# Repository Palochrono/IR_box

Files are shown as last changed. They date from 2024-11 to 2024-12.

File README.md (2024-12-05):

# IR_box
Normally open (HIGH) keychron low profile optical hitbox
Keychron switches footprint from [here](https://github.com/girishji/keychron-optical-keyboard?tab=MIT-1-ov-file)
## Part list
| Component | Description | Number_used |
| --- | --- | --- |
| R_IR | 180 $\Omega$ 0805 | 16 |
| R_PT | 2k $\Omega$ 0603 | 16 |
| Phototransistor | 0805 | 16 |
| IR_led | 0805 | 16 |
| Rp2040-zero | Waveshare | 1 |
| Pushbutton | 6*6mm | 4 |
| Key switches | Keychron optical low profile | 16 |
| OLED display | 0.96 inch I2C SSD1306 | 1 |
| Keycap set | DOIO KCGM-02 KCGM-03| 1 |
## Schematics and Render
Half-vias used to use the extra pins in rp2040-zero






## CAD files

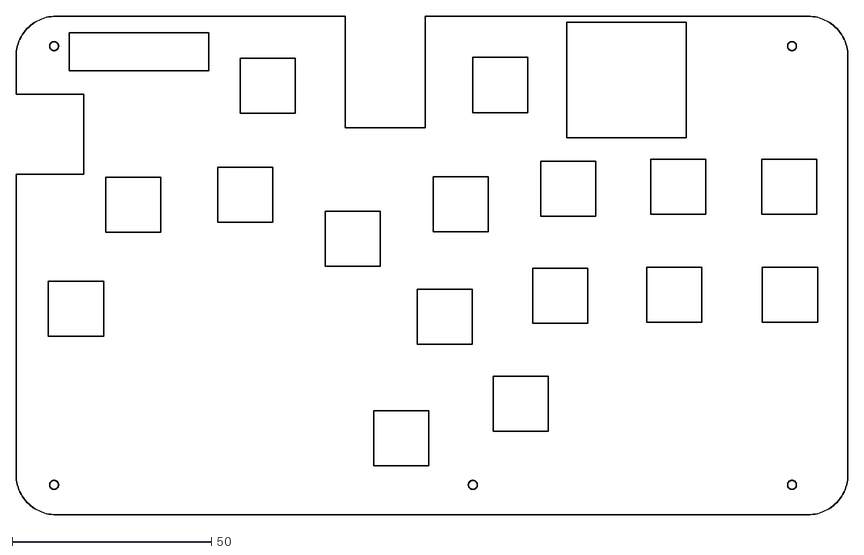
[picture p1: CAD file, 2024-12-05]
3d_files/dxf_files/switch_plate_1mm.dxf
208.5 x 125.0

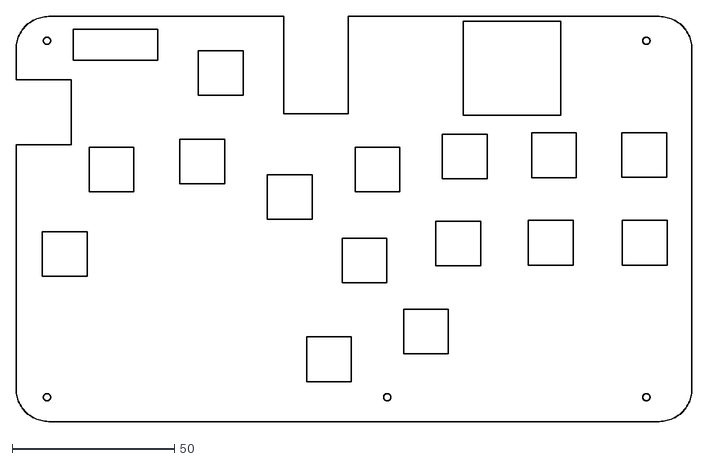
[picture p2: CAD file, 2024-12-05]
3d_files/dxf_files_1.0/switch_plate_1mm.dxf
208.5 x 125.0

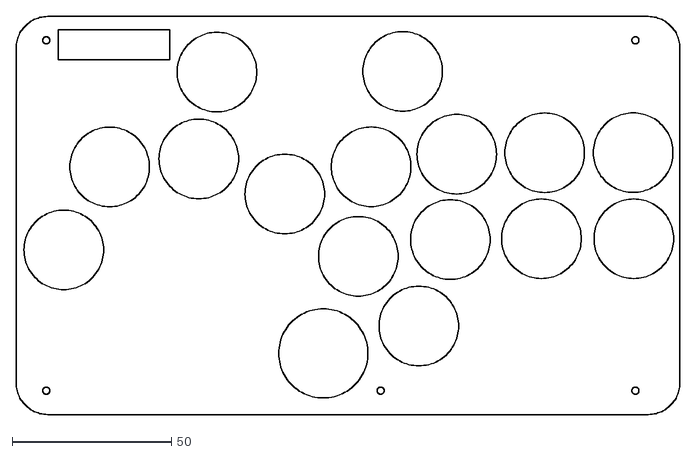
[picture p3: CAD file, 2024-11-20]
3d_files/top_cover_1.5mm.dxf
208.5 x 125.0

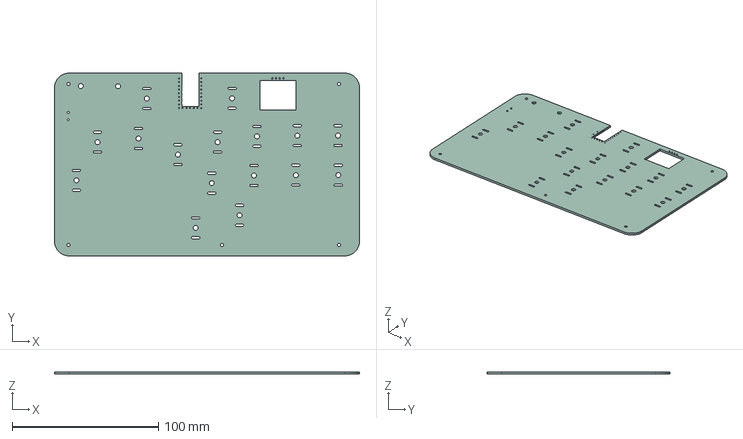
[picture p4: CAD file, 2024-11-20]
kicad/keychron_hitbox.step
208.5 x 125.0 x 1.69 mm

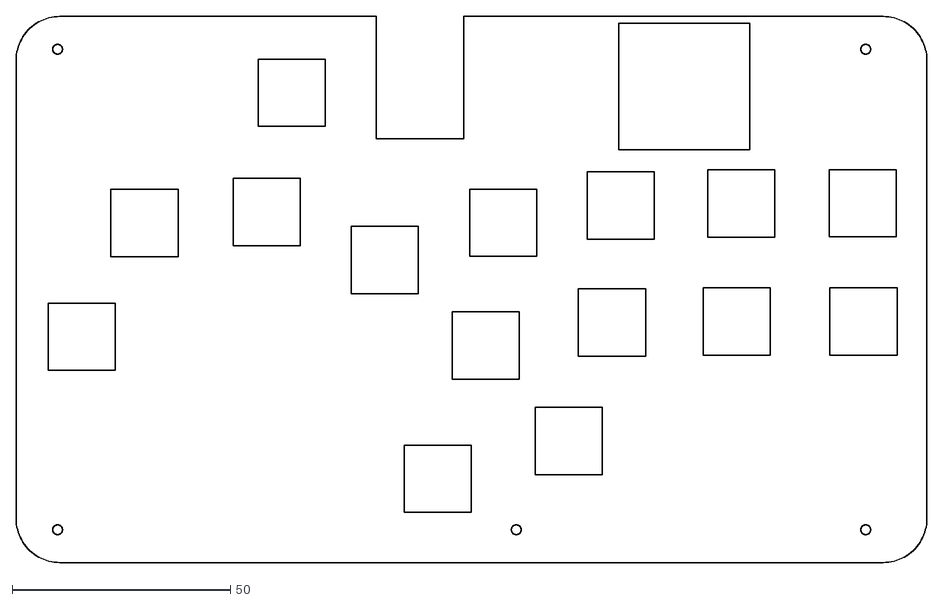
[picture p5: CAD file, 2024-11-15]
3d_files/dxf_files/switch_back_space_2mm.dxf
208.5 x 125.0

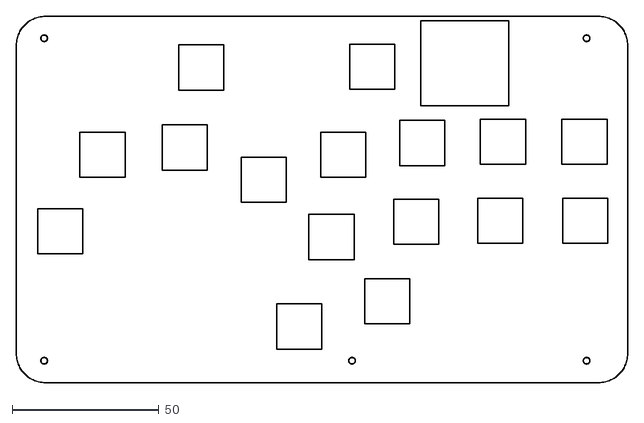
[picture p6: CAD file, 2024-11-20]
3d_files/dxf_files_upload/switch_back_space_1.5mm.dxf
208.5 x 125.0

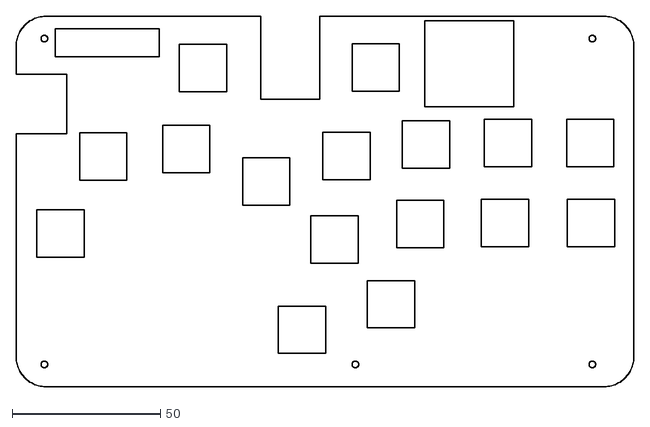
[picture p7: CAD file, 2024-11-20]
3d_files/switch_front_space_1.5mm.dxf
208.5 x 125.0

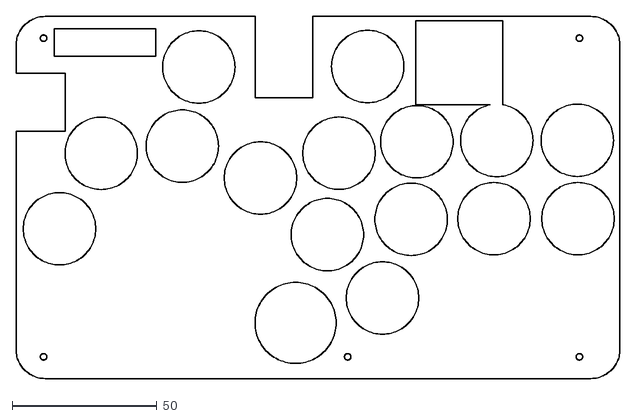
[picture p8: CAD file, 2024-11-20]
3d_files/switch_top_cover_space_4mm.dxf
208.5 x 125.0

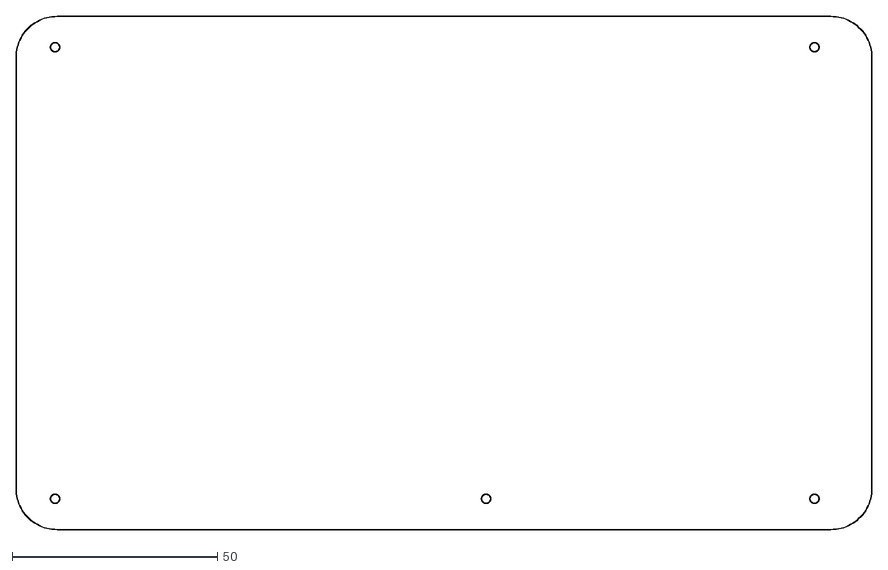
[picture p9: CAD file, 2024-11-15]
3d_files/dxf_files_upload/bottom_cover_1mm.dxf
208.5 x 125.0

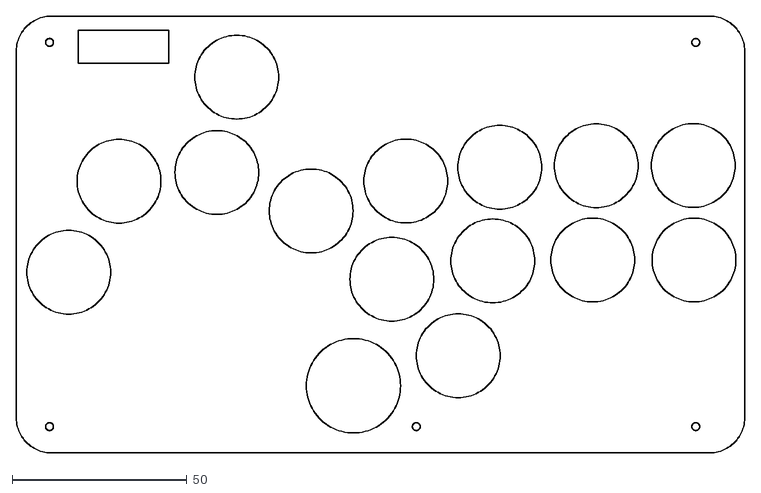
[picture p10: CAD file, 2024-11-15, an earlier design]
3d_files/older_version/dxf_files/top_cover_1.5mm.dxf
208.5 x 125.0

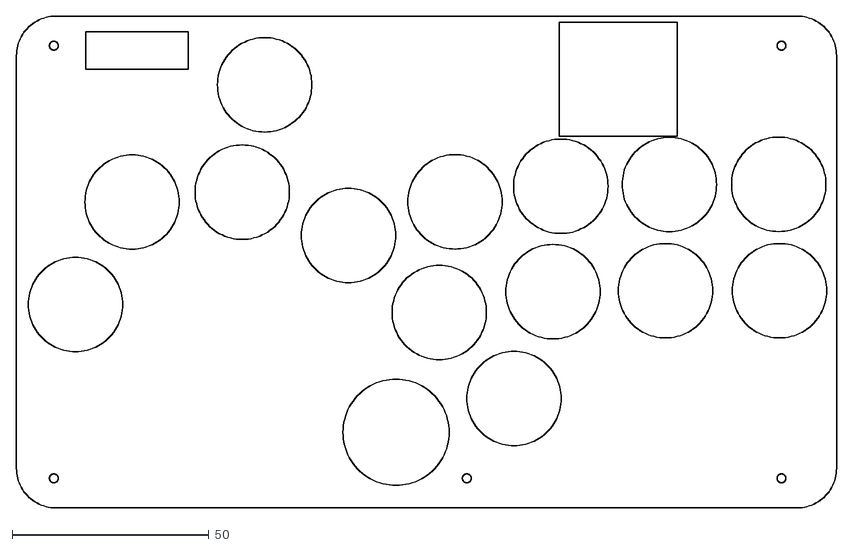
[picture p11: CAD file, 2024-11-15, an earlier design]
3d_files/older_version/dxf_files/switch_top_cover_space_4mm.dxf
208.5 x 125.0

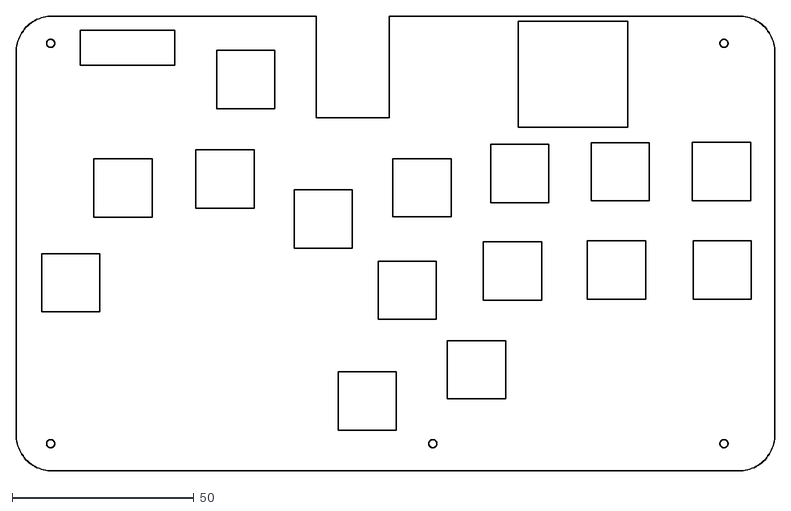
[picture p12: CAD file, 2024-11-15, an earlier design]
3d_files/older_version/dxf_files/switch_front_space_1.5mm.dxf
208.5 x 125.0

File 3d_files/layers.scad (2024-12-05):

$fn = 100;
module pcb(){
    translate([-43,150,0])
    import("/home/samz/programming/kicad/IR_box/kicad/Unnamed.stl");
}


module plainbase(x_size=208.5,y_size=125,corner_radius=10){
    translate([corner_radius,corner_radius,0])
    offset(r=corner_radius)
    square([x_size-2*corner_radius,y_size-2*corner_radius]);
}
//plainbase();

module hole(x_offset,y_offset,radius){
    translate([x_offset,y_offset,0])
    circle(radius);
}

module switch_plate_imprint(size = 13.8, catch_x = 3, catch_y=0){
    difference(){
        square(size, center=true);
        translate([0,size/2,0])
        square([catch_x,catch_y*2], center=true);
        translate([0,-size/2,0])
        square([catch_x,catch_y*2], center=true);
    }
}
module switch_plate_imprints(pos_array){
    for (a = [ 0 : len(pos_array) - 1 ]) 
    {
        point=pos_array[a];
        translate([point[0],point[1],0])
        switch_plate_imprint();
    }
}

module holes(pos_array,radius){
    for (a = [ 0 : len(pos_array) - 1 ]) 
    {
        point=pos_array[a];
        hole(point[0],point[1],radius);
    }
}

module squares(pos_array,size){
    for (a = [ 0 : len(pos_array) - 1 ]) 
    {
        point=pos_array[a];
        translate([point[0],point[1],0])
        square(size, center = true);
    }
}

screw_locations = [[9.5,7.5],[114.5,7.5],[194.5,7.5],[9.5,117.5],[194.5,117.5]];
//switch_locations = [[15,51.7],[29.4,77.75],[57.4,80.25],[63.1,107.55],[84.4,69.25],[107.5,49.685],[136.4,54.95],[165,55.2],[194,55.2],[193.8,82.25],[166,82.2],[138.4,81.75],[111.5,77.8],[126.5,27.8],[121.4,107.75]];
switch_locations = [[15,51.7],[29.4,77.75],[57.4,80.25],[63.1,107.55],[84.4,69.25],[107.5,49.685],[136.4,54.95],[165,55.2],[194,55.2],[193.8,82.25],[166,82.2],[138.4,81.75],[111.5,77.8],[126.5,27.8]];
jump_locations =[[96.5,19.2]];
//push_button_locations = [[27.,116.1],[34.55,116.1],[43.5,116.1],[18,116.1]];
push_button_locations = [[30.55,116.275],[38.9,116.275],[22.4,116.275]];

module push_button_holes(){
    squares(push_button_locations, 9.5);
    //squares(push_button_locations, 2.5);
}

module screw_holes(){
    holes(screw_locations, 1.12);
}
module 23mm_switch_circular(){
    holes(switch_locations, 12.5);
    //holes(switch_locations, 1.5);
}

module 26mm_switch_circular(){
    holes(jump_locations, 14);
}

module switches_back_slots(){
    squares(switch_locations, 15.4);
    squares(jump_locations, 15.4);
}

module switches_front_slots(){
    squares(switch_locations, 16);
    squares(jump_locations, 16);
}

module switch_plate_holes(){
    switch_plate_imprints(switch_locations);
    switch_plate_imprints(jump_locations);
}

module pi_imprint(){
    translate([82.5,97,0])
    square([20,28]);
}
module pi_imprint(){
    translate([82.5,95,0])
    square([20,30]);
}

module oled_imprint(){
    translate([138,94.5,0])
    square([30,29]);
}
module usb_imprint(){
    translate([0,85.4])
    square([17,20]);
}


module top_cover(){
    difference(){
        plainbase();
        push_button_holes();
        26mm_switch_circular();
        23mm_switch_circular();
        screw_holes();
    }
}
module bottom_cover(){
    difference(){
        plainbase();
        screw_holes();
    }
}
module switch_back_space(){
    difference(){
        plainbase();
        screw_holes();
        switches_back_slots();
        oled_imprint();
    }
}
module switch_front_space(){
    difference(){
        plainbase();
        push_button_holes();
        screw_holes();
        switches_front_slots();
        pi_imprint();
        oled_imprint();
        usb_imprint();
    }
}
module switch_front_plate(){
    difference(){
        plainbase();
        push_button_holes();
        screw_holes();
        switch_plate_holes();
        oled_imprint();
        pi_imprint();
        usb_imprint();
    }
}
module switch_top_cover_space(){
    difference(){
        plainbase();
        push_button_holes();
        26mm_switch_circular();
        23mm_switch_circular();
        screw_holes();
        oled_imprint();
        usb_imprint();
        pi_imprint();
    }
}

module testing_holes(){
    translate([10,50,0])
    switch_plate_imprint(size = 13.6, catch_x = 3, catch_y=0.2);
    translate([30,50,0])
    switch_plate_imprint(size = 13.7, catch_x = 3, catch_y=0.2);
    translate([50,50,0])
    switch_plate_imprint(size = 13.8, catch_x = 3, catch_y=0.2);
    translate([70,50,0])
    switch_plate_imprint(size = 13.9, catch_x = 3, catch_y=0.2);
    translate([90,50,0])
    switch_plate_imprint(size = 14.0, catch_x = 3, catch_y=0.2);
    translate([110,50,0])
    switch_plate_imprint(size = 14.1, catch_x = 3, catch_y=0.2);
    translate([130,50,0])
    switch_plate_imprint(size = 14.2, catch_x = 3, catch_y=0.2);
    translate([150,50,0])
    switch_plate_imprint(size = 14.3, catch_x = 3, catch_y=0.2);
    translate([170,50,0])
    switch_plate_imprint(size = 14.4, catch_x = 3, catch_y=0.2);
    translate([190,50,0])
    switch_plate_imprint(size = 14.5, catch_x = 3, catch_y=0.2);
}

module plate_test(){
    difference(){
        plainbase();
        push_button_holes();
        screw_holes();
        pi_imprint();
        oled_imprint();
        testing_holes();
    }
}
//bottom_cover();
//switch_back_space();
//switch_front_space();
switch_front_plate();
//switch_top_cover_space();
//pcb();
//top_cover();
//plate_test();

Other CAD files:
kicad/3d_files/layers.scad
kicad/Unnamed-keychron_hitbox.scad
3d_files/switch_plate_1mm.dxf

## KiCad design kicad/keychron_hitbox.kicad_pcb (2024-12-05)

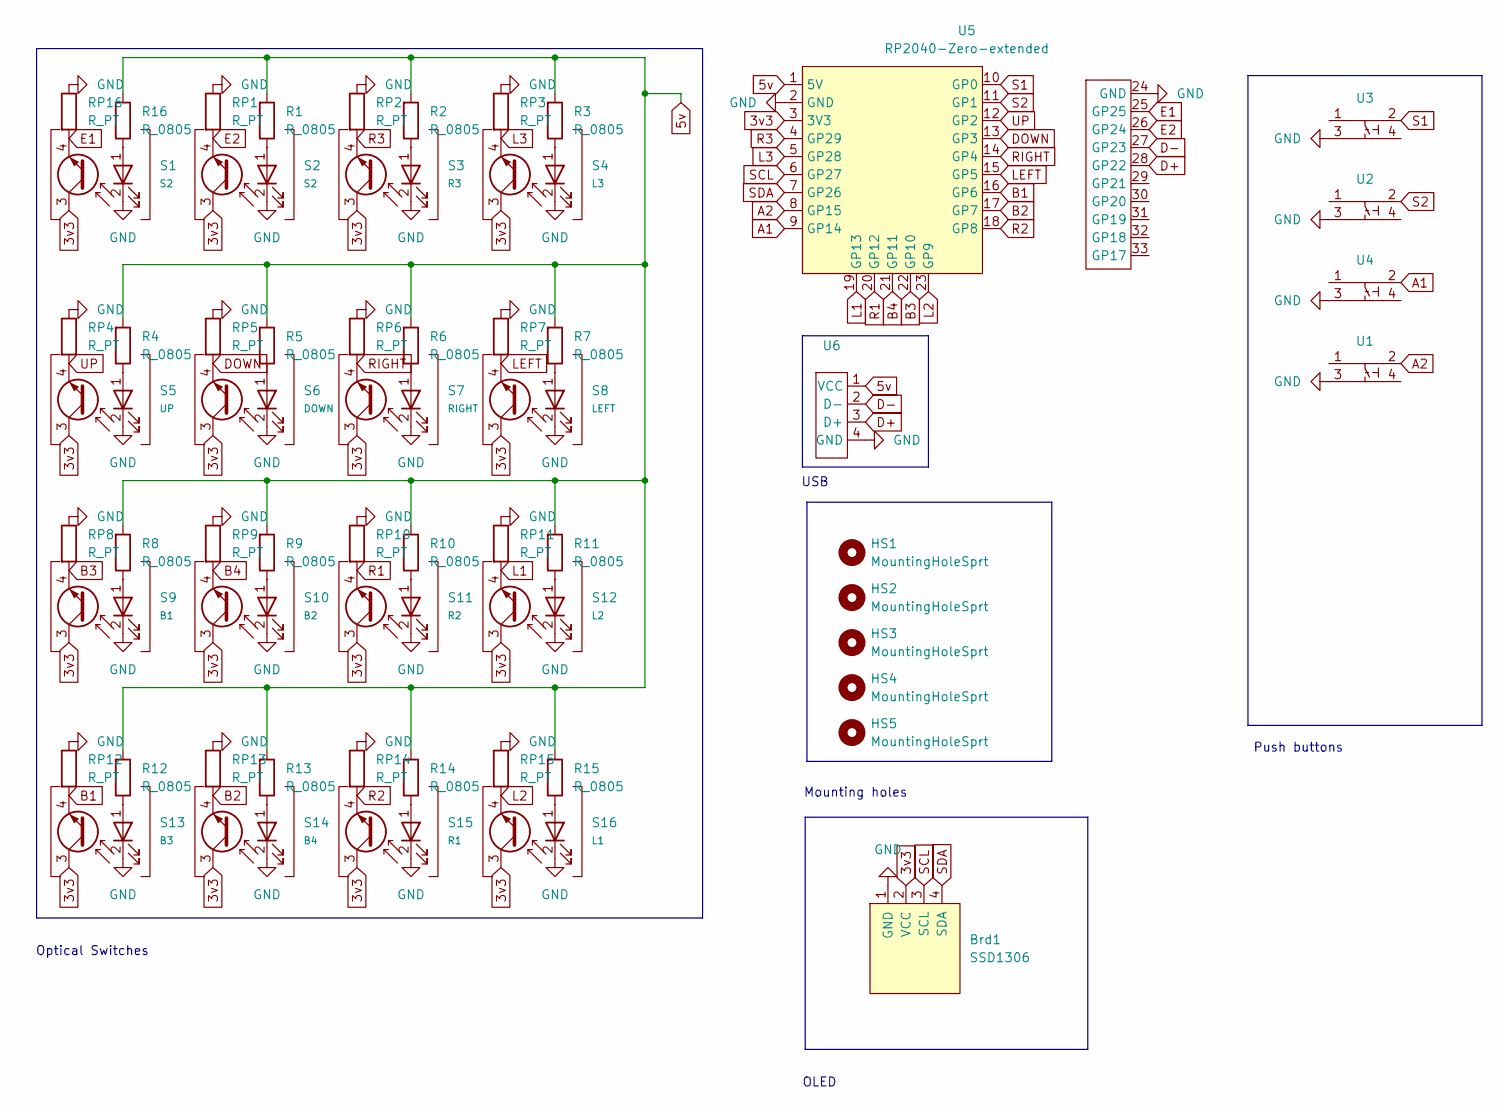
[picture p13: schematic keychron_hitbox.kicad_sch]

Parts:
Brd1: SSD1306; 128x64OLED_hollowed
HS1, HS2, HS3, HS4, HS5: MountingHoleSprt; MountingHole_2.2mm_M2_ISO7380_Pad
R1, R2, R3, R4, R5, R6, R7, R8, R9, R10, R11, R12, R13, R14, R15, R16: R_0805; R_0805_2012Metric
RP1, RP2, RP3, RP4, RP5, RP6, RP7, RP8, RP9, RP10, RP11, RP12, RP13, RP14, RP15, RP16: R_PT; R_0603; JLC 0805-2012
S1, S2: S2; Keychron_Optical_Switch_23mm
S3: R3; Keychron_Optical_Switch_23mm
S4: L3; Keychron_Optical_Switch_23mm
S5: UP; Keychron_Optical_Switch_26mm
S6: DOWN; Keychron_Optical_Switch_23mm
S7: RIGHT; Keychron_Optical_Switch_23mm
S8: LEFT; Keychron_Optical_Switch_23mm
S9: B1; Keychron_Optical_Switch_23mm
S10: B2; Keychron_Optical_Switch_23mm
S11: R2; Keychron_Optical_Switch_23mm
S12: L2; Keychron_Optical_Switch_23mm
S13: B3; Keychron_Optical_Switch_23mm
S14: B4; Keychron_Optical_Switch_23mm
S15: R1; Keychron_Optical_Switch_23mm
S16: L1; Keychron_Optical_Switch_23mm
U1, U2, U3, U4: 6x6pushbutton
U5: RP2040-Zero-extended; RP2040 Zero zllpin
U6: usba_header

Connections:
3v3: Brd1.2 (VCC), S1.3 (C), S2.3 (C), S3.3 (C), S4.3 (C), S5.3 (C), S6.3 (C), S7.3 (C), S8.3 (C), S9.3 (C), S10.3 (C), S11.3 (C), S12.3 (C), S13.3 (C), S14.3 (C), S15.3 (C), S16.3 (C), U5.3 (3V3)
5v: R1.1, R2.1, R3.1, R4.1, R5.1, R6.1, R7.1, R8.1, R9.1, R10.1, R11.1, R12.1, R13.1, R14.1, R15.1, R16.1, U5.1 (5V), U6.1 (VCC)
A1: U4.2, U5.9 (GP14)
A2: U1.2, U5.8 (GP15)
B1: RP12.2, S13.4 (E), U5.16 (GP6)
B2: RP13.2, S14.4 (E), U5.17 (GP7)
B3: RP8.2, S9.4 (E), U5.22 (GP10)
B4: RP9.2, S10.4 (E), U5.21 (GP11)
D+: U5.28 (GP22), U6.3 (D+)
D-: U5.27 (GP23), U6.2 (D-)
DOWN: RP5.2, S6.4 (E), U5.13 (GP3)
E1: RP16.2, S1.4 (E), U5.25 (GP25)
E2: RP1.2, S2.4 (E), U5.26 (GP24)
GND: Brd1.1 (GND), RP1.1, RP2.1, RP3.1, RP4.1, RP5.1, RP6.1, RP7.1, RP8.1, RP9.1, RP10.1, RP11.1, RP12.1, RP13.1, RP14.1, RP15.1, RP16.1, S1.2 (IR_K), S2.2 (IR_K), S3.2 (IR_K), S4.2 (IR_K), S5.2 (IR_K), S6.2 (IR_K), S7.2 (IR_K), S8.2 (IR_K), S9.2 (IR_K), S10.2 (IR_K), S11.2 (IR_K), S12.2 (IR_K), S13.2 (IR_K), S14.2 (IR_K), S15.2 (IR_K), S16.2 (IR_K), U1.3, U2.3, U3.3, U4.3, U5.2 (GND), U5.24 (GND), U6.4 (GND)
L1: RP11.2, S12.4 (E), U5.19 (GP13)
L2: RP15.2, S16.4 (E), U5.23 (GP9)
L3: RP3.2, S4.4 (E), U5.5 (GP28)
LEFT: RP7.2, S8.4 (E), U5.15 (GP5)
unnamed: R16.2, S1.1 (IR_A)
unnamed: R1.2, S2.1 (IR_A)
unnamed: R2.2, S3.1 (IR_A)
unnamed: R3.2, S4.1 (IR_A)
unnamed: R4.2, S5.1 (IR_A)
unnamed: R5.2, S6.1 (IR_A)
unnamed: R6.2, S7.1 (IR_A)
unnamed: R7.2, S8.1 (IR_A)
unnamed: R8.2, S9.1 (IR_A)
unnamed: R9.2, S10.1 (IR_A)
unnamed: R10.2, S11.1 (IR_A)
unnamed: R11.2, S12.1 (IR_A)
unnamed: R12.2, S13.1 (IR_A)
unnamed: R13.2, S14.1 (IR_A)
unnamed: R14.2, S15.1 (IR_A)
unnamed: R15.2, S16.1 (IR_A)
R1: RP10.2, S11.4 (E), U5.20 (GP12)
R2: RP14.2, S15.4 (E), U5.18 (GP8)
R3: RP2.2, S3.4 (E), U5.4 (GP29)
RIGHT: RP6.2, S7.4 (E), U5.14 (GP4)
S1: U3.2, U5.10 (GP0)
S2: U2.2, U5.11 (GP1)
SCL: Brd1.3 (SCL), U5.6 (GP27)
SDA: Brd1.4 (SDA), U5.7 (GP26)
UP: RP4.2, S5.4 (E), U5.12 (GP2)

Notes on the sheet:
USB
Push buttons
Optical Switches
Mounting holes
OLED

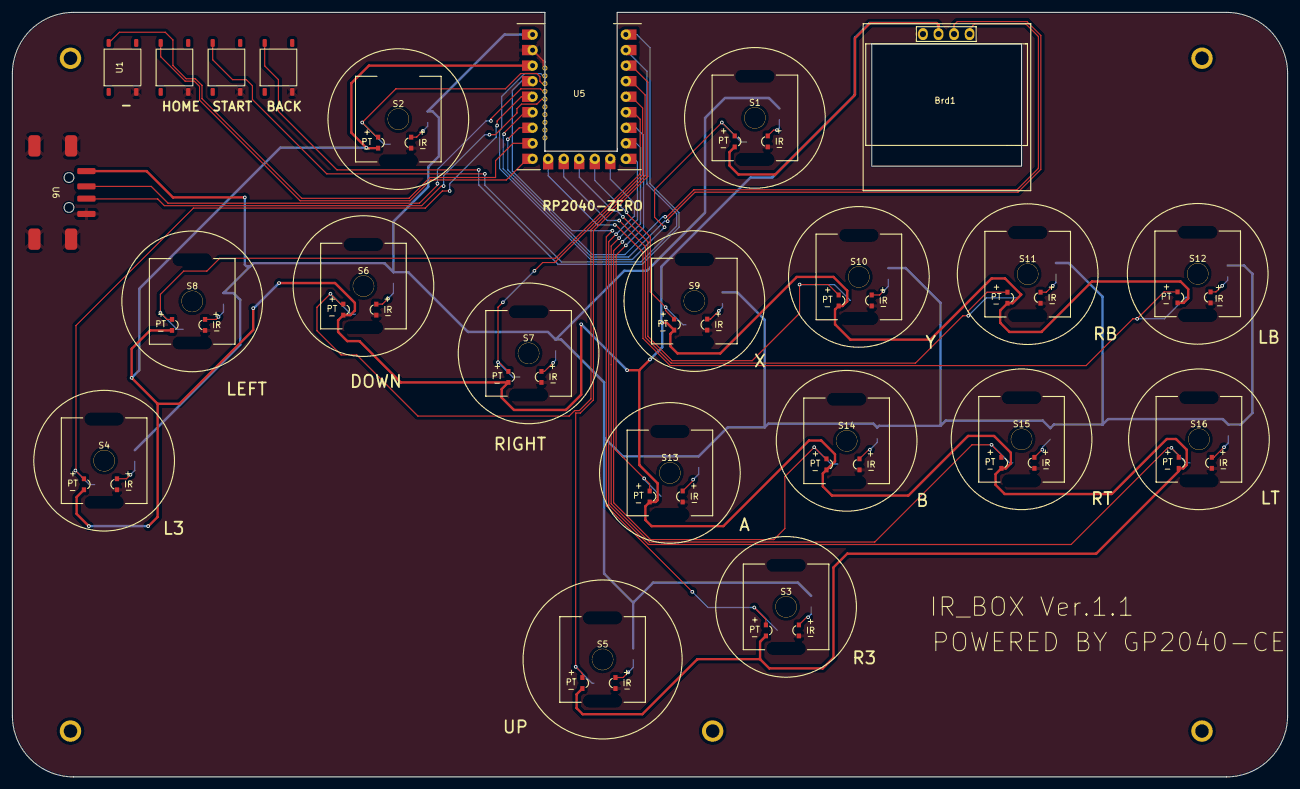
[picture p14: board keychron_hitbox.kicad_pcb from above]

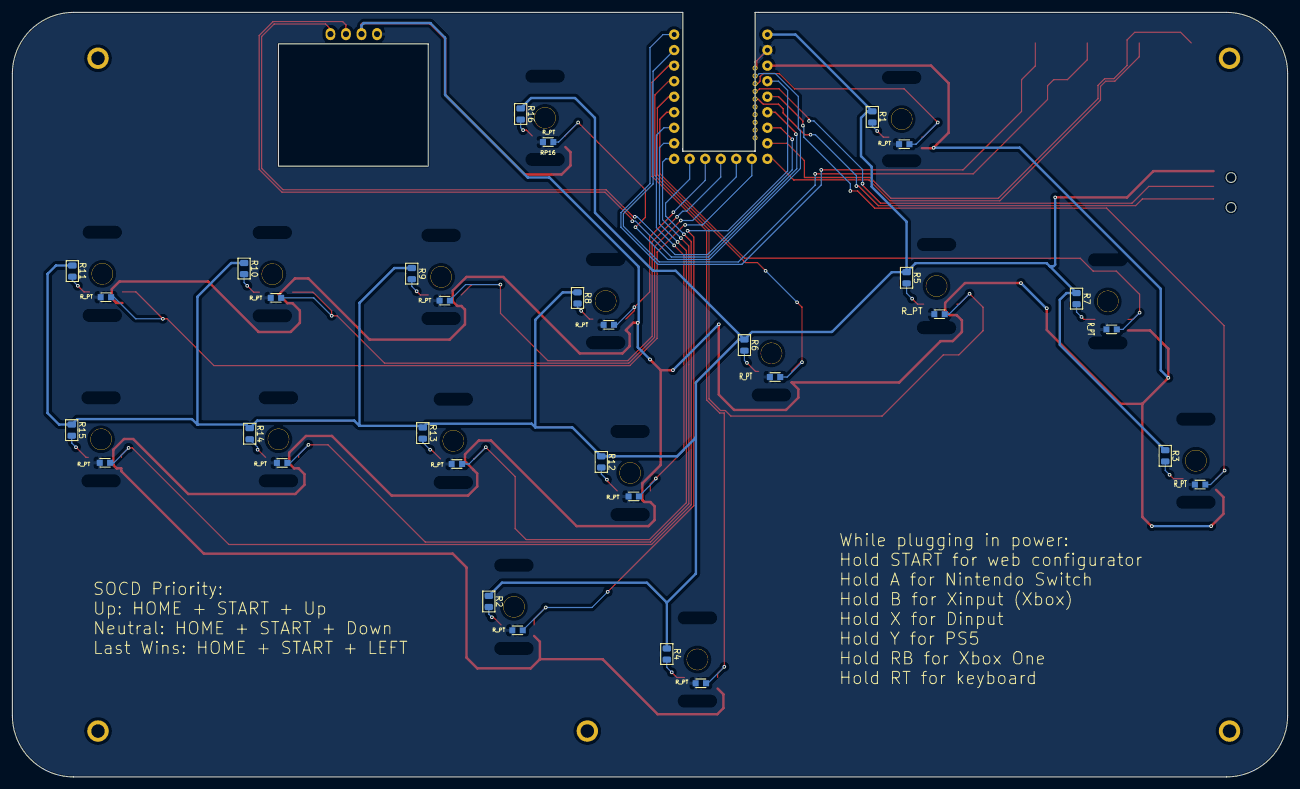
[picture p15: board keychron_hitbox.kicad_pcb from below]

Board: 2 copper layers, 208.5 x 125.0 mm, 60 parts (32 on the bottom side), 43 nets.

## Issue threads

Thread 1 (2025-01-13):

Sourcing IR / PT pairs

superami-code, 2025-01-13:
I am trying to put together my own board using the low profile Keychron keys and I was wondering which parts you used. There seem to be several potential candidates, but most seem to be barely fitting or too tight. I also looked into 0603 sized side fire parts, but while I've found two manufacturers (KTRLight and ALLight), neither have distributors.

Palochrono, 2025-04-02:
Anything smaller than 0805 should work with Keychron switches. I used 0805 photo transistors and emitters with solder pads on the side, unfortunately there are no branding on the parts I got. The ones I got have a half-cylindrical plastic bit that focuses the light. They fit in the optical switches pretty well as long as they are soldered properly to the pcb. Also the Keychron switches footprint I used is unchanged from [this project](https://github.com/girishji/keychron-optical-keyboard) which I mentioned in README.

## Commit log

2024-11-09 initial upload
    [keychron_hitbox-B_Cu.gbl, keychron_hitbox-B_Mask.gbs, keychron_hitbox-B_Paste.gbp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]
2024-11-14 updated seating for OLED & some acrylic designs
    [keychron_hitbox.kicad_pcb, keychron_hitbox.kicad_sch, layers.scad]
2024-11-20 adding version 1.1
    [Unnamed-keychron_hitbox.scad, bottom_cover_1mm.dxf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]
2024-12-05 fix 3d file keyswitch plate
    [bottom_cover_1mm.dxf, keychron_hitbox.kicad_pcb, layers.scad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]
